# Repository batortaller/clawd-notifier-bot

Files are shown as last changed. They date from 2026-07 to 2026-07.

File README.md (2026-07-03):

# Clawd Notifier Bot

A little servo **flag** (plus the board's onboard RGB LED) that tells you what
Claude Code is doing, from across the room:

| State | Trigger (Claude Code hook) | Flag | LED |
|---|---|---|-----|
| **Wants your attention** — finished, needs permission, or asked a question | `Stop`, `Notification` | up (180°) | solid **white** |
| **Working / thinking** — after each tool call, or you sent a new prompt | `PostToolUse`, `UserPromptSubmit` | down (0°) | pulses **white** (⅓ Hz) |
| **Acknowledged** | button press | down (0°) | off |

Attention requests are **ref-counted**: if several are still pending, clearing one
dips the arm and raises it again so you can tell there's more waiting.

Press the button once to lower the flag ("I saw it"). **Triple-press within 2 s**
to make the arm dance and flash the LED through a color show. 🎉

## Hardware

- [Waveshare RP2040-Zero](https://www.waveshare.com/wiki/RP2040-Zero).
- [MG90S](https://components101.com/motors/mg90s-metal-gear-servo-motor) 180 degree servo motor.
- Low profile keyboard switch (can be bought cheap from Aliexpress)
- 330uF capacitor

| Part | Pin | Notes |
|---|-----|---|
| Servo (signal) | `GP29` | Hobby servo, 50 Hz, 500–2500 µs |
| Servo (power) | `5V` / `VBUS` | **Not `3V3`** — that routes motor current through the regulator and can kill the board |
| Push button | `GP0` → button → `GND` | Uses the internal pull-up; no resistor needed |
| RGB LED | `GP16` (`board.NEOPIXEL`) | Onboard WS2812, driven by the built-in `neopixel_write` |

Powering the servo from USB works, but a servo is an inductive motor: solder a
**bulk capacitor (200–1000 µF) on the RP2040 board's 5V and GND port to absorb current
spikes and back-EMF. Without it, rapid motion (like the dance) can brown out or
damage the board.

## Repository layout

| File | What it is |
|---|---|
| `code.py` | The firmware — servo + LED state machine, button handling, dance |
| `boot.py` | Sets a custom USB identity and renames the drive to `CLAWDBOT` |
| `README.board.md` | Short end-user README deployed onto the board's drive as `README.md` |
| `servo_notify.py` | Host-side hook script; sends a one-byte command to the board over USB serial |
| `install.sh` | Installs `servo_notify.py` (into an isolated venv) and registers the Claude Code hooks |
| `uninstall.sh` | Reverses `install.sh`: removes the hooks, script, venv, and state (recoverable — backs up + trashes) |
| `flash.sh` | One-command flasher: firmware + files + rename, no BOOTSEL button needed |
| `cp_waveshare_rp2040_zero-10.2.1.uf2` | The exact CircuitPython build this is tested against |

## Quick start

### 1. Flash a board

```bash
bash flash.sh
```

Plug the board in (already-running boards are dropped into the bootloader over
USB automatically — no need to hold BOOTSEL). The script flashes CircuitPython,
copies all project files, and renames the drive to `CLAWDBOT`.

Requires **pyserial** on a working Python. `flash.sh` auto-detects an
interpreter that has it and falls back to `/usr/bin/python3`. If none is found:

```bash
/usr/bin/python3 -m pip install --user pyserial
```

### 2. Wire the button

One leg to the `GP0` pad, the other to any `GND` pad.

### 3. Hook it up to Claude Code

```bash
bash install.sh
```

This installs the hook script into an isolated venv under `~/.claude/hooks/` (so
it never touches an externally-managed system/Homebrew Python) and registers four
hooks in `~/.claude/settings.json`: `Stop` + `Notification` → raise,
`UserPromptSubmit` + `PostToolUse` → lower.

To remove everything again:

```bash
bash uninstall.sh
```

It backs up `settings.json` and moves removed files to the Trash first, and leaves
the board's firmware untouched.

## How it works

The host hooks send a single byte to the board over USB serial; `code.py` reads
it in its main loop:

| Byte | Meaning | Result |
|---|---|---|
| `1` | attention (finished / needs you) | flag up, LED solid white |
| `2` | thinking / working | flag down, LED pulses white |
| `0` | idle | flag down, LED off |

`servo_notify.py` ref-counts attention on the host: `up` sends `1` (solid white);
`down` sends `2` (working pulse) once nothing is pending, or dips (`0`→`1`) when
attention is still pending. The mode is cached so the frequent `PostToolUse`
`down` only refreshes the pulse once instead of hitting the port every tool call.

A button press is handled entirely on the board (single = acknowledge/lower,
triple within 2 s = dance).

## Tuning (all at the top of `code.py`)

| Constant | Purpose |
|---|---|
| `REVERSED` | Flip if the servo turns the wrong way |
| `THINK_HZ` | Thinking-pulse rate (default ⅓ Hz) |
| `IDLE_ANGLE` / `ALERT_ANGLE` | Flag down/up positions |
| `TRIPLE_WINDOW_S` / `TRIPLE_COUNT` / `DEBOUNCE_S` | Triple-press gesture |
| `DANCE_MOVES` / `DANCE_COLORS` / `DANCE_STEP_S` | Dance choreography |

## Limitations

This integrates with **Claude Code** (the CLI), which exposes lifecycle *hooks*.
The Claude **desktop app** has no equivalent hook system, so it can't drive the
board.

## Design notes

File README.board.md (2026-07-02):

# Clawd Notifier Bot

A little servo flag + onboard LED that shows what Claude Code is doing.

- **Flag UP + solid white LED** — Claude wants your attention: it finished,
  needs permission, or asked you a question.
- **Flag DOWN + pulsing white** — Claude is working / thinking.
- **Flag DOWN + LED off** — idle / acknowledged (button press).

Button (wired `GP0` → button → `GND`):

- **Press once** — lower the flag ("I saw it").
- **Triple-press within 2 s** — make the arm dance. 🎉

## Setup

1. Plug the board into USB.
2. Install the Claude Code hook:
   ```bash
   bash install.sh
   ```
3. That's it — finish a task and watch the flag go up.

To remove it later: `bash uninstall.sh`.

Full docs & source: https://github.com/batortaller/clawd-notifier-bot

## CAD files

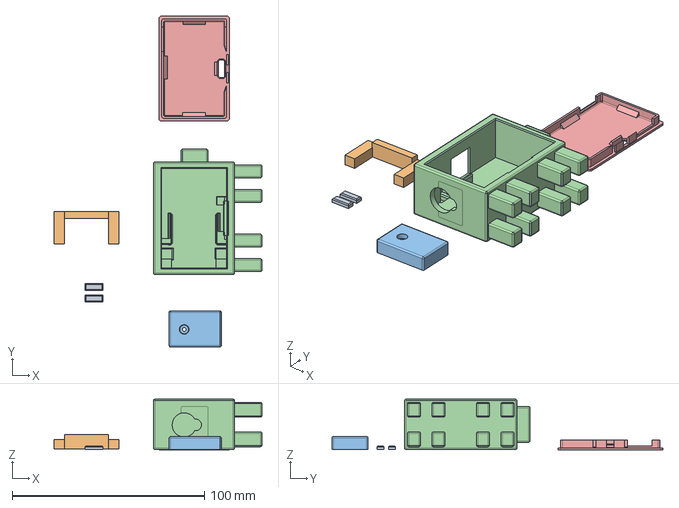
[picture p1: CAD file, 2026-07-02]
models/ClawdBot.step
108.1 x 172.2 x 26.3 mm

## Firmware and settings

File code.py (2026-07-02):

# code.py — CircuitPython servo notifier (runs on the RP2040-Zero).
#
# Servo flag for Claude Code:
#   0   = resting / default
#   180 = Claude finished a task
# Lowers on a command byte "0" (next prompt) or an acknowledge button press.
# Triple-press the button within 2 s to make the arm dance and flash the LED.
import board
import pwmio
import digitalio
import neopixel_write
import supervisor
import sys
import time
import math

SERVO_PIN = board.GP29
BUTTON_PIN = board.GP0          # external acknowledge button to GND
PWM_FREQ_HZ = 50

MIN_PULSE_US = 500
MAX_PULSE_US = 2500
PERIOD_US = 1_000_000 // PWM_FREQ_HZ

IDLE_ANGLE = 0
ALERT_ANGLE = 180
SETTLE_MS = 600

# Flip if the servo turns the wrong way (mirrors every angle end-to-end).
REVERSED = True

# While Claude is thinking, pulse the LED white at this rate (Hz).
# 1/3 Hz = one full fade up-and-down every 3 seconds.
THINK_HZ = 1 / 3

# Triple-press "dance": three debounced presses inside this window triggers it.
TRIPLE_WINDOW_S = 2.0
TRIPLE_COUNT = 3
DEBOUNCE_S = 0.05               # ignore contact bounce between counted presses

# Dance choreography: paired servo angles and onboard-LED colors (R, G, B).
DANCE_MOVES = (
    30, 150, 60, 120, 0, 180, 90,
    45, 135, 75, 160, 20, 110, 90,
)
DANCE_COLORS = (
    (255, 0, 0), (0, 255, 0), (0, 0, 255), (255, 255, 0),
    (0, 255, 255), (255, 0, 255), (255, 255, 255),
    (255, 128, 0), (128, 0, 255), (0, 255, 128), (255, 0, 128),
    (128, 255, 0), (0, 128, 255), (255, 255, 255),
)
DANCE_STEP_S = 0.22

pwm = pwmio.PWMOut(SERVO_PIN, frequency=PWM_FREQ_HZ)

# Onboard WS2812 RGB LED (GP16). Driven directly via the core neopixel_write
# module so no external library is required.
led = digitalio.DigitalInOut(board.NEOPIXEL)
led.direction = digitalio.Direction.OUTPUT


def led_rgb(r, g, b):
    # The WS2812 expects color bytes in GRB order.
    neopixel_write.neopixel_write(led, bytearray((g, r, b)))


def set_angle(angle):
    angle = max(0, min(180, angle))
    if REVERSED:
        angle = 180 - angle
    pulse = MIN_PULSE_US + (MAX_PULSE_US - MIN_PULSE_US) * angle // 180
    pwm.duty_cycle = int(pulse * 65535 // PERIOD_US)


# Non-blocking move: command the angle now and schedule the "relax" (stop
# sending pulses to kill buzz/holding current) for later, so the main loop
# stays responsive enough to catch rapid button presses.
relax_at = None


def command_angle(angle):
    global relax_at
    set_angle(angle)
    relax_at = time.monotonic() + SETTLE_MS / 1000


def move_to(angle):
    # Blocking move — used at startup and inside the dance, where the loop
    # doesn't need to stay responsive.
    set_angle(angle)
    time.sleep(SETTLE_MS / 1000)
    pwm.duty_cycle = 0


def show_alert():
    # Claude finished: raise the flag and light the LED white.
    led_rgb(255, 255, 255)
    command_angle(ALERT_ANGLE)


def show_idle():
    # Resting / acknowledged: lower the flag and turn the LED off.
    led_rgb(0, 0, 0)
    command_angle(IDLE_ANGLE)


def dance():
    for angle, color in zip(DANCE_MOVES, DANCE_COLORS):
        led_rgb(*color)
        set_angle(angle)
        time.sleep(DANCE_STEP_S)
    led_rgb(0, 0, 0)            # lights off
    move_to(IDLE_ANGLE)        # settle back home and relax


# Start in the resting position with the LED off.
move_to(IDLE_ANGLE)
led_rgb(0, 0, 0)

# Acknowledge button: reads HIGH via pull-up, LOW when pressed to GND.
button = digitalio.DigitalInOut(BUTTON_PIN)
button.switch_to_input(pull=digitalio.Pull.UP)

prev_pressed = False
press_times = []
thinking = False                       # pulse the LED white while Claude works

while True:
    n = supervisor.runtime.serial_bytes_available
    if n:
        data = sys.stdin.read(n)
        if "0" in data:
            thinking = False
            show_idle()
        elif "2" in data:              # Claude is thinking / working
            thinking = True
            command_angle(IDLE_ANGLE)  # flag stays down while it works
        elif data:  # "1" or any other byte -> finished / needs you
            thinking = False
            show_alert()

    pressed = not button.value
    if pressed and not prev_pressed:
        now = time.monotonic()
        # Debounce, then keep only the presses still inside the window.
        if not press_times or now - press_times[-1] >= DEBOUNCE_S:
            press_times = [t for t in press_times if now - t <= TRIPLE_WINDOW_S]
            press_times.append(now)
            if len(press_times) >= TRIPLE_COUNT:
                thinking = False
                dance()
                press_times = []
                relax_at = None        # dance already relaxed the servo
            else:
                thinking = False
                show_idle()
    prev_pressed = pressed

    # While thinking, pulse the LED white at THINK_HZ (smooth 0->full->0).
    if thinking:
        level = (1 - math.cos(2 * math.pi * THINK_HZ * time.monotonic())) / 2
        v = int(255 * level)
        led_rgb(v, v, v)

    # Non-blocking relax once the servo has had time to reach its target.
    if relax_at is not None and time.monotonic() >= relax_at:
        pwm.duty_cycle = 0
        relax_at = None

    time.sleep(0.02)

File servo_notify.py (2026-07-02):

#!/usr/bin/env python3
# servo_notify.py — installed to ~/.claude/hooks/servo_notify.py
#
# Sends a one-byte command to the servo notifier over USB serial:
#   up   (default) -> "1" : raise the flag, solid white LED (Claude wants your
#                           attention: finished, needs permission, or asking)
#   down           -> Claude is working: "2" -> flag down + pulsing white LED,
#                     unless attention is still pending, in which case the flag
#                     dips ("0" then "1") to signal there's more waiting.
#
# Exits 0 even if the board is missing so it never adds noise to Claude Code.
import os
import sys
import json
import time
import serial
import serial.tools.list_ports

# A freshly opened USB CDC port isn't ready to transmit immediately: on macOS
# the first bytes after open are often dropped before the host/device finish
# negotiating. Wait this long after opening before writing.
OPEN_SETTLE_S = 0.3
# Retry open/write a few times so a momentarily busy port (another hook still
# closing, the CIRCUITPY editor, the board mid-move) doesn't drop the signal.
ATTEMPTS = 4
RETRY_DELAY_S = 0.25
# When a down still leaves work pending, lower the arm then raise it again after
# this pause so the dip is physically visible — and so the board reads the two
# bytes as separate commands instead of coalescing "01" into a single lower.
DIP_PAUSE_S = 0.7

# boot.py on the board gives it a custom USB identity (vendor id 0x1209 from
# pid.codes, product "Robot", manufacturer "Clawd"). Match the vendor id first,
# then fall back to the product/manufacturer strings.
NOTIFIER_VID = 0x1209
PRODUCT_HINTS = ("Robot", "Clawd")

# Persisted state: how many "attention" requests are pending ("up" increments,
# "down" decrements — the flag is up while count > 0) plus the LED mode currently
# shown on the board ("attention" or "working"). Tracking the mode lets the
# frequent PostToolUse "down" refresh the working pulse once and then no-op,
# instead of hitting the serial port on every tool call.
STATE_FILE = os.path.join(os.path.dirname(os.path.abspath(__file__)), ".servo_state")


def read_state():
    try:
        with open(STATE_FILE) as f:
            raw = f.read().strip()
    except OSError:
        return 0, ""
    try:
        data = json.loads(raw)
        return max(0, int(data.get("count", 0))), str(data.get("mode", ""))
    except (ValueError, AttributeError):
        try:
            return max(0, int(raw)), ""   # legacy format: a bare integer count
        except ValueError:
            return 0, ""


def write_state(count, mode):
    try:
        with open(STATE_FILE, "w") as f:
            json.dump({"count": max(0, count), "mode": mode}, f)
    except OSError:
        pass


def find_port():
    for port in serial.tools.list_ports.comports():
        if port.vid == NOTIFIER_VID:
            return port.device
        haystack = " ".join(
            filter(None, (port.description, port.product, port.manufacturer))
        )
        if any(hint in haystack for hint in PRODUCT_HINTS):
            return port.device
    return None


def send_sequence(steps):
    # Open the port and play a list of (byte, pause_after_s) steps in one session.
    # Returns True once the bytes are handed off, False if the board is missing or
    # never frees up. Best-effort: the caller tracks the pending count regardless.
    for attempt in range(ATTEMPTS):
        # Re-resolve the port each attempt: it can disappear/reappear (e.g. the
        # board re-enumerates) between tries.
        port = find_port()
        if not port:
            time.sleep(RETRY_DELAY_S)
            continue
        try:
            with serial.Serial(port, 115200, timeout=1) as s:
                time.sleep(OPEN_SETTLE_S)      # let the CDC link come up
                for byte, pause in steps:
                    s.write(byte)
                    s.flush()                  # block until the OS hands off the byte
                    time.sleep(0.05)           # let it actually drain
                    if pause:
                        time.sleep(pause)
            return True
        except serial.SerialException:
            time.sleep(RETRY_DELAY_S)          # port busy; back off and retry
    return False


def main():
    arg = sys.argv[1].lower() if len(sys.argv) > 1 else "up"
    up = arg not in ("down", "lower", "idle", "0")
    count, mode = read_state()

    if up:
        # Attention request (Stop / Notification): count it and raise the flag,
        # solid white. "up" is always sent, so a flag lowered out-of-band by the
        # GP0 button comes back up.
        write_state(count + 1, "attention")
        send_sequence([(b"1", 0)])
        sys.exit(0)

    # "down" = Claude is working now (UserPromptSubmit / PostToolUse).
    if count > 0:
        count -= 1
        if count > 0:
            # One attention cleared but more remain: dip the flag and raise it
            # again so you can tell there's still something waiting.
            write_state(count, "attention")
            send_sequence([(b"0", DIP_PAUSE_S), (b"1", 0)])
        else:
            # Nothing pending anymore -> show the "thinking" pulse.
            write_state(0, "working")
            send_sequence([(b"2", 0)])
        sys.exit(0)

    # Already nothing pending. Refresh the working pulse once, then let the
    # frequent PostToolUse "down" no-op so we don't spam the serial port.
    if mode != "working":
        write_state(0, "working")
        send_sequence([(b"2", 0)])
    sys.exit(0)  # board missing or never free -> state still updated; stay quiet


if __name__ == "__main__":
    main()

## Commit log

2026-07-02 Initial commit: Clawd notifier bot
    Servo-flag + onboard-LED notifier for Claude Code on a Waveshare
    RP2040-Zero (CircuitPython). Raises a flag when Claude finishes or needs
    input, pulses the LED while it works, and dances on a triple button-press.
    Includes the firmware (code.py/boot.py), the host hook (servo_notify.py),
    the hook installer (install.sh), and a one-command flasher (flash.sh).
2026-07-02 Separate board README from repo README
    flash.sh was deploying the repo's full README.md onto the board's drive.
    Add a concise board-facing README.board.md and have flash.sh copy it to
    the drive as README.md, leaving README.md as the repository documentation.
2026-07-02 flash.sh: fix header comment for board README
2026-07-02 Host-side rework: venv interpreter, ref-counted flag, uninstall
    Integrates a colleague's improvements to the host tooling:
    - install.sh: install pyserial into an isolated venv under ~/.claude/hooks
    (never touches an externally-managed system/Homebrew Python), point the
    hook command at that venv's python, and upgrade stale hook entries in
    place. Adds a PostToolUse -> down hook.
    - servo_notify.py: ref-count pending "attention" requests in a state file so
    the flag stays up while work remains and "dips" (lower then raise) when one
    of several clears; the frequent PostToolUse "down" is a cheap no-op when
    nothing is pending.
    - uninstall.sh (new): reverses install.sh, backing up setting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
    [servo_notify.py]
2026-07-02 Wire the thinking-pulse into the ref-count model
    servo_notify.py now sends byte "2" (LED pulses white, flag down) whenever
    Claude is working with no attention pending — i.e. the "down" events
    (UserPromptSubmit / PostToolUse). Attention (Stop / Notification) still sends
    "1" (solid white, flag up), and a down that leaves other requests pending
    still dips.
    The displayed mode is cached in the state file so the frequent PostToolUse
    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
2026-07-02 Add Clawd 3D models
    [ClawdBot.step]
2026-07-02 Update README with MG90S servo motor details
    Added information about the MG90S servo motor.
2026-07-03 Revise hardware details and capacitor recommendations
    Updated hardware section with additional components and capacitor specifications.
